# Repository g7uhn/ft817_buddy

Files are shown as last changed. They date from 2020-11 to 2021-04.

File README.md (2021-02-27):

# ft817_buddy
A companion display &amp; controls for the FT-817.

FT817 Buddy Rev 1 in the field

This is a work in progess, [more information at my page](http://alloutput.com/ft-817-buddy/).

A little story about the build is over at [SWLing Post](https://swling.com/blog/2020/08/andy-builds-a-genius-companion-control-display-for-the-yaesu-ft-817-transceiver/).

Rev4 hardware files now released :-)

Enjoy!

<br />This work is licensed under a <a rel="license" href="http://creativecommons.org/licenses/by-sa/4.0/">Creative Commons Attribution-ShareAlike 4.0 International License</a>.

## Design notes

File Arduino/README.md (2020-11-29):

Arduino files for the FT817_buddy project

This folder conatins sub-folders for:
- src - the main Arduino sketch
- lib - non-standard libraries used by the sketch that you will need to import into your IDE

<br />This work is licensed under a <a rel="license" href="http://creativecommons.org/licenses/by-sa/4.0/">Creative Commons Attribution-ShareAlike 4.0 International License</a>.

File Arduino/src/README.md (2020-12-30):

The main Arduino sketch for the FT-817 Buddy project.

This sketch has been built using Visual Studio Code / PlatformIO IDE (instead of Arduino IDE).  If you want to load this code into Arduino IDE you probably just need to remove the #include <Arduino.h> line at the top of the sketch, Google is your friend.  But it's much nicer to work in VSC/PlatformIO, it's a nice step forward from the Arduino IDE.

Don't forget to inmport the non-standard ft817 library into your IDE, found under ft817_buddy/Arduino/lib/

### Current features

- Display current frequency and mode
- Display current A,B,C key functions
- 3 pages of 6 soft-keys
- Backlight
- Clock
- Tune signal on/off (Transmit an AM carrier, suitable for driving auto-ATU)
- Toggle IPO
- Toggle NAR filter
- Toggle Break-In
- Toggle FT-817 internal Keyer
- Toggle RF Gain/ Squelch
- Toggle VFO A/B
- Set FT-817 internal keyer to preset wpm (12, 15, 18 in my case)
- External keyer: [K1EL K16 chip](https://hamcrafters2.com/files/k16man_R10.pdf) integration
  - Command and M1, M2, M3, M4 buttons
  - Onboard piezo buzzer and LED for K16 feedback
  - Control speed using CMD+paddle (K1EL's "Fast Speed Change" feature)

### Licence
<br />This work is licensed under a <a rel="license" href="http://creativecommons.org/licenses/by-sa/4.0/">Creative Commons Attribution-ShareAlike 4.0 International License</a>.

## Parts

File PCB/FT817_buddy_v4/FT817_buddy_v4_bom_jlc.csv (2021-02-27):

Comment | Designator | Footprint | LCSC Part #
100nF | C1,C3,C5,C4,C10,C6 | C_0805_2012Metric_Pad1.15x1.40mm_HandSolder | C49678
10uF | C2 | C_0805_2012Metric_Pad1.15x1.40mm_HandSolder | C15850
10nF | C7 | C_0805_2012Metric_Pad1.15x1.40mm_HandSolder | C1710
1nF | C8,C9 | C_0805_2012Metric_Pad1.15x1.40mm_HandSolder | C46653
Polyfuse_Small | F1 | Fuse_1206_3216Metric_Pad1.42x1.75mm_HandSolder | C369154
47k | R2,R6 | R_0805_2012Metric_Pad1.15x1.40mm_HandSolder | C17713
10k | R3,R4 | R_0805_2012Metric_Pad1.15x1.40mm_HandSolder | C17414
22k | R5 | R_0805_2012Metric_Pad1.15x1.40mm_HandSolder | C17560
100k | R7 | R_0805_2012Metric_Pad1.15x1.40mm_HandSolder | C17407
10K | R8,R10,R11,R16 | R_0805_2012Metric_Pad1.15x1.40mm_HandSolder | C17414
1K | R9,R18,R20,R22 | R_0805_2012Metric_Pad1.15x1.40mm_HandSolder | C17513
2.2K | R12,R13,R14,R15,R1 | R_0805_2012Metric_Pad1.15x1.40mm_HandSolder | C17520
220 | R17 | R_0805_2012Metric_Pad1.15x1.40mm_HandSolder | C17557
470 | R19 | R_0805_2012Metric_Pad1.15x1.40mm_HandSolder | C17710
1500 | R21 | R_0805_2012Metric_Pad1.15x1.40mm_HandSolder | C4310
AMS1117-5.0 | U1 | SOT-223-3_TabPin2 | C6187
ADuM1201AR | U3 | SOIC-8_3.9x4.9mm_P1.27mm | C9669
ULN2803A | U5 | SOIC-18W_7.5x11.6mm_P1.27mm | C9683

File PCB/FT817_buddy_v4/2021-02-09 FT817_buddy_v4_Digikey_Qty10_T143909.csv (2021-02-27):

Index | Quantity | Part Number | Manufacturer Part Number | Description | Customer Reference | Available | Backorder | Unit Price | Extended Price GBP
1 | 20 | CKN9559-ND | OS102011MA1QN1 | SWITCH SLIDE SPDT 100MA 12V |  | 20 | 0 | 0.34100 | 6.82
2 | 10 | 2725-B0505S-1WR3-ND | B0505S-1WR3 | DC DC CONVERTER 5V 1W |  | 10 | 0 | 0.86500 | 8.65
3 | 10 | 490-9647-1-ND | PKMCS0909E4000-R1 | AUDIO PIEZO TRANSDUCER 12.5V SMD |  | 10 | 0 | 0.59000 | 5.90
4 | 20 | CP1-3525N-ND | SJ1-3525N | CONN JACK STEREO 3.5MM R/A |  | 20 | 0 | 0.48900 | 9.78
5 | 50 | 754-1939-1-ND | APT2012LZGCK | LED GREEN CLEAR 2SMD |  | 50 | 0 | 0.28000 | 14.00
6 | 10 | 609-4717-ND | DILB8P-223TLF | CONN IC DIP SOCKET 8POS TIN |  | 10 | 0 | 0.11100 | 1.11

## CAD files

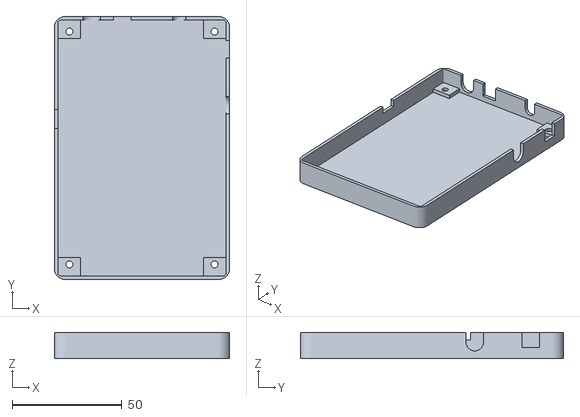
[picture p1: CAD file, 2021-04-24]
Enclosure/enclosure_base_Rev4_v1.stl
80.0 x 120.0 x 12.0

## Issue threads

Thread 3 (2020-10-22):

Brief fluctuations in displayed data

drorthogonal, 2020-10-22:
The display occasionally updates with missing data or incorrect data, for just a few milli seconds, before reverting to the correct info. This is seen in two places while on the 2nd Page (speed change page).
1. Filter display switches from "CW N" to "???N".
2. Frequency display, displays random changes to the Mhz, KHz or 100s Hz or all three.

g7uhn, 2020-10-22:
Yes, these seem to be single read errors from the serial input, recovered on the next poll of the item.  I suspect the read errors are down to use of SoftwareSerial.  Note that the FT-817 serial interface should be using 2 stop bits (8N2) but SoftwareSerial can only do 8N1.  We seem to get away with just 1 stop bit but maybe this is the result.  I've also seen reports that SoftwareSerial can produce relatively frequent read errors... other software serial libraries are available.

Possible ways forward:
- Do nothing.  It's occasional at 9600 baud, probably tolerable.  But at 38400 baud the errors appear frequently;
- Use an alternate software serial library e.g. [NeoSWSerial](https://www.arduino.cc/reference/en/libraries/neoswserial/);
- Move to a microcontroller that has a dedicated hardware serial port for the radio interface.

g7uhn, 2020-11-07:
Moved to hardware serial on Rev2 - looks rock solid now.  :-)

Closed 2020-11-07.

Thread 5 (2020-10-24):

Keyer speed selection

drorthogonal, 2020-10-24:
The current keyer speed options (page 2) are set up at compile time and not configurable from the FT817 Buddy.
This issue is to investigate a possible evolution to this to provide some more flexibility. Options include:
1. Providing a way to configure  and store user preferences for the speeds (would need a way to store values persistently). Probably beyond the scope of this project.
2. Read the current Keyer speed and provide 6 x soft key options (3 x slower and 3 x faster) e.g. if current keyer speed is 18wpm provide softly options for, say, 12, 14, 16, 20, 22 & 24wpm.
3. Read and display the current Keyer speed settings and provide [up] [down] options on the soft keys to increment or decrement the speed in, say, 1wpm steps, reloading the display with the newly set speed.
#enhancement
...I'm adding this one as a possible development for me to try to learn C++!

g7uhn, 2020-11-07:
Good enhancement... might be solved by integration of a K1EL keyer onto the Buddy... let's wait and see how we feel when we try that.

g7uhn, 2020-11-17:
Including the K1EL K16 keyer chip... the CMD+paddle speed adjustment seems to hit points 2 and 3

g7uhn, 2020-11-21:
I think we're there for a first pass at this.

- K1EL external keyer added to Rev3, powers up at a preset favourite wpm and speed +/- is controlled by CMD+paddle, beeps for feedback, see [K16 manual](https://hamcrafters2.com/files/k16man_R10.pdf), page 15, "Fast Speed Change Feature"
- If using the FT-817 internal keyer (unlikely after the addition of K1EL) then preset favourite speeds can be programmed/ modified into Buddy code easily (current code is an example)
- More complex read/modify of the internal keyer is possible if someone wants to put the time in... :smile:

Closed 2020-11-21.

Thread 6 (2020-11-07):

Reduce current draw from FT-817

g7uhn, 2020-11-07:
FT-817 ACC port "13.8V" output pin appears to have a current-limiting 10 Ohm 1/16W 0604-size resistor between it and the radio's 13.8V supply rail.  It's very small so it may be there as a fuse...?  **Translates to 0.0625W or about 5mA @13V.** 😟
(resistor power handling and consequences are noted here: https://www.microwavers.org/files/backscatter/8_IF-Rigs.pdf ...and the Yaesu service manual does indeed show R1235 is a 10 Ohm 1/16W 0604)

But wait!  A note on KA7OEI's site says *"if you leave the CT-62 CAT interface cable plugged into the '817, this will pull 20-30 milliamps from the radio's power source"* ...which suggest that Yaesu's own accessory pulls up to 30mA... and the BHI CAT-MATE suggests you can pull up to 60mA from the port (http://noisecancellingintercom.co.uk/html/cat-mate.html) so maybe 20mA is a very reasonable design target after all?

Anyway, at some point my radio appears to have started struggling to supply much power to this pin (Buddy wouldn't power up completely, Arduino stuck in constant reboot cycle) so I may have exceeded what this resistor is there to limit.  Measured current draw of the Buddy at that time was around 40mA @ 10.5V.  I've solved it by performing the VK4GHZ mod.  Other users will wish to use the Buddy without modifying their radio so we need to aim for lowest possible current draw.

Other, more obvious, motivation to reduce current draw of the Buddy is to not waste battery power when portable.

Arduino Pro Mini (Rev2) draws almost exactly the same current as Arduino Nano (despite what the Internet suggests).

Note the Buddy includes a polyfuse immediately after the voltage input to the PCB to protect the FT-817 supply but there is always a small chance of short-circuit before that fuse causing damage to the FT-817.

To do:
- Prototype SMPS modules on breadboard with blink Arduino sketch (removes pulsed serial noise)
- Search for birdies and raised noise level using an antenna

g7uhn, 2020-11-07:
SMPS modules from Murata and CUI on order for exploratory test

g7uhn, 2020-11-15:
SMPS module tested (muRata) - only reduced current from 30mA to 25mA... adds complex part, difficult to install, risk of RFI... doesn't feel like the juice is worth the squeeze.

g7uhn, 2020-11-26:
The CatDisplay accessory pulls a whopping 130mA from the 817 CAT port!  https://sites.google.com/site/zl1cvd/catdisplay

So I feel pretty good about the 40mA of the Buddy.

Closed 2020-11-15.

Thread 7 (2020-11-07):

Improve main loop

g7uhn, 2020-11-07:
Need slicker timing on the main loop
- make tuning display appear smoother
- make all buttons appear equally responsive
- recognise button press and release so we can "hold down" an output to the K1EL CMD input

Maybe more use of interrupts?
Do more reading on good use of Arduino switches e.g. http://www.martyncurrey.com/switching-things-on-and-off-with-an-arduino/

Closed 2020-11-27.

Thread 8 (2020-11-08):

K1EL Keyer Integration Design

g7uhn, 2020-11-08:
- Determine how the Arduino could drive the K1EL buttons
  - A quad low-side driver would bethe way to go here... but I can't find a quad at reasonable price/size so it's a ULN2803A
- Determine how to best drive a piezo (include some smoothing caps? suggested in K16 manual), compare some piezos for a decent sound
  - Sound examples, +free samples+ and fancy square buzzers: https://www.murata.com/en-global/products/sound/sounder/play
  - What effect does mounting a slim buzzer on the *underside* of the PCB have? Might smooth and/or amplify the sound? But would these benefits go away once an enclosure arrives?
- Slim TRS sockets: https://www.mouser.co.uk/ProductDetail/Schurter/48322330?qs=M1T3mF8ombUPfMcVAC0H1Q%3D%3D
- Suitable 10k linear pots on Mouser: https://www.mouser.co.uk/Passive-Components/Potentiometers-Trimmers-Rheostats/Potentiometers/_/N-9q0ypZ1yzvvqx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

Rough sketch of possible Rev3 layout:
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

Closed 2020-11-08.

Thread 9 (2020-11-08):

K1EL Keyer Integration Code and Test

g7uhn, 2020-11-08:
- Write code to drive keyer buttons
- Determine how to best drive a piezo on breadboard (include some smoothing caps? suggested in K16 manual), compare some piezos for a decent sound
- What effect does mounting a slim buzzer on the underside of the PCB have? Might smooth and/or amplify the sound? But would these benefits go away once an enclosure arrives?

g7uhn, 2020-11-15:
Buzzer working OK direct from K16 sidetone pin to "+" pin.

Buttons driving K16 input pin - needed some experimentation to compensate for the 0.6V volt drop across the low-side driver switching... +need to experiment with better resistor selection and find the edges of K16 decisions+

g7uhn, 2020-11-17:
- Probably settled on resistors.
- Operation more reliable by ditching the speed knob (simplify the resistor network where we have to guess at the transistor switching effects).  CMD+paddle adjustment of the keyer speed feels good!

Closed 2020-11-21.

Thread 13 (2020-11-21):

Pick an open source licence for this project

g7uhn, 2020-11-21:
No inherited licences in this project at this time... except requests for a nod to authors (which is done in the docs, source code and PCB silkscreen).

Licences of interest:
[CC-by-sa (share alike)](https://creativecommons.org/licenses/by-sa/4.0/)
...works for hardware and software

g7uhn, 2020-11-21:
http://www.inmojo.com/licenses/#cc_a_sa_3.0 Description of CC-BY-SA license under Open Source HardWare (OSHW) definition

Closed 2020-11-21.

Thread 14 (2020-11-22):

Documentation

g7uhn, 2020-11-22:
FAQ
Build guide (order the stuff, build it)
Operating notes (subject to change with the code improving)
Design notes
Data pack (schematic, PCB files)
License notes (why it's CC-BY-SA)
Software guide (notes on the Arduino pinout and interfaces, general guide to the sketch and library usage, how to add a feature on the code, how to join in on GitHub)

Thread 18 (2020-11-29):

Investigate serial number generator

g7uhn, 2020-11-29:
Something like enter your callsign, get a serial number...
...write your serial number on your PCB
...callsigns are stored just to see how many of these things are out in the wild
Doesn't mean anything, just for fun!

g7uhn, 2020-11-29:
Wordpress plugin:
- Contact Form 7
- CF7 Google Sheets Connector
- Contact Form 7 Serial Numbers

Sounds complicated but the idea that something goes straight into a Google Sheet is cool.

g7uhn, 2020-11-29:
Concerned that giving out "serial numbers" rather implies some sort of warranty/liability

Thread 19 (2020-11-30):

Rev3 PCB improvements

g7uhn, 2020-11-30:
- ~~Is there a way to support both AZD (8-pin) and Sparkfun (9-pin) displays?~~
- ~~Check tx keying of FT-817 (actual TX, there was some mention of RFI on keying in the K16 doc)~~
- ~~Increase OSHW symbol size~~
- ~~Increase "+" size next to buzzer (may not be necessary?)~~
- ~~Add a 1k resistor in between Arduino and buzzer?  see Murata [data sheet](https://www.murata.com/products/productdata/8801054228510/SPEC-PKMCS0909E4000-R1.pdf?1590156016000)~~
- ~~Consider easier to solder buzzer? Only if terrible feedback from testers...~~
- ~~Improve labelling around cable J1 e.g. Rx, Tx...~~
- ~~Increase clearance of ground plane around cable header J1 for peace of mind, reduce risk of V to G short before fuse~~
- ~~Draw box around B0505~~
- Move callsigns away from tracks where possible
- ~~Licence text and symbol on rear silkscreen?~~
- ~~Move LED pads away from clip holes~~
- ~~Swap 3.5mm socket for through-hole part~~
- ~~Swap left and right paddle inputs to be normal~~

Closed 2021-02-07.

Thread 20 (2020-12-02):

Read currentMode on startup

g7uhn, 2020-12-02:
...so that an accidental press of TUNoff doesn't flick the radio into LSB if you haven't done a TUNon

Or only activate TUNoff if TUNon has been pressed. (toggle a bool)

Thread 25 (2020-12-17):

Add a UTC clock onto the board

g7uhn, 2020-12-17:
Could be a RTC added to the Nokia screen items? (probably requires a coin battery and other stuff adding to the PCB...)
Could be just a separate LCD clock mounted on the board?
Or just buy a cheap digital watch and stick it on the 817?

g7uhn, 2020-12-22:
Will require an RTC IC and a button battery (and a few other passive components) adding to the PCB.
Will also significantly increase complexity of code (need a menu screen for setting the time).
Probably skip this to keep the project simple.  Just add a cheap LCD clock velcro'd to the top of the radio...?

Closed 2020-12-22.

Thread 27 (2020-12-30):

Improve clock accuracy

g7uhn, 2020-12-30:
Currently loses 1 minute every 2.5h

g7uhn, 2021-02-08:
Good enough for non-RTC operation.
RTC now implemented, tested overnight, no time slip.

Closed 2021-02-08.

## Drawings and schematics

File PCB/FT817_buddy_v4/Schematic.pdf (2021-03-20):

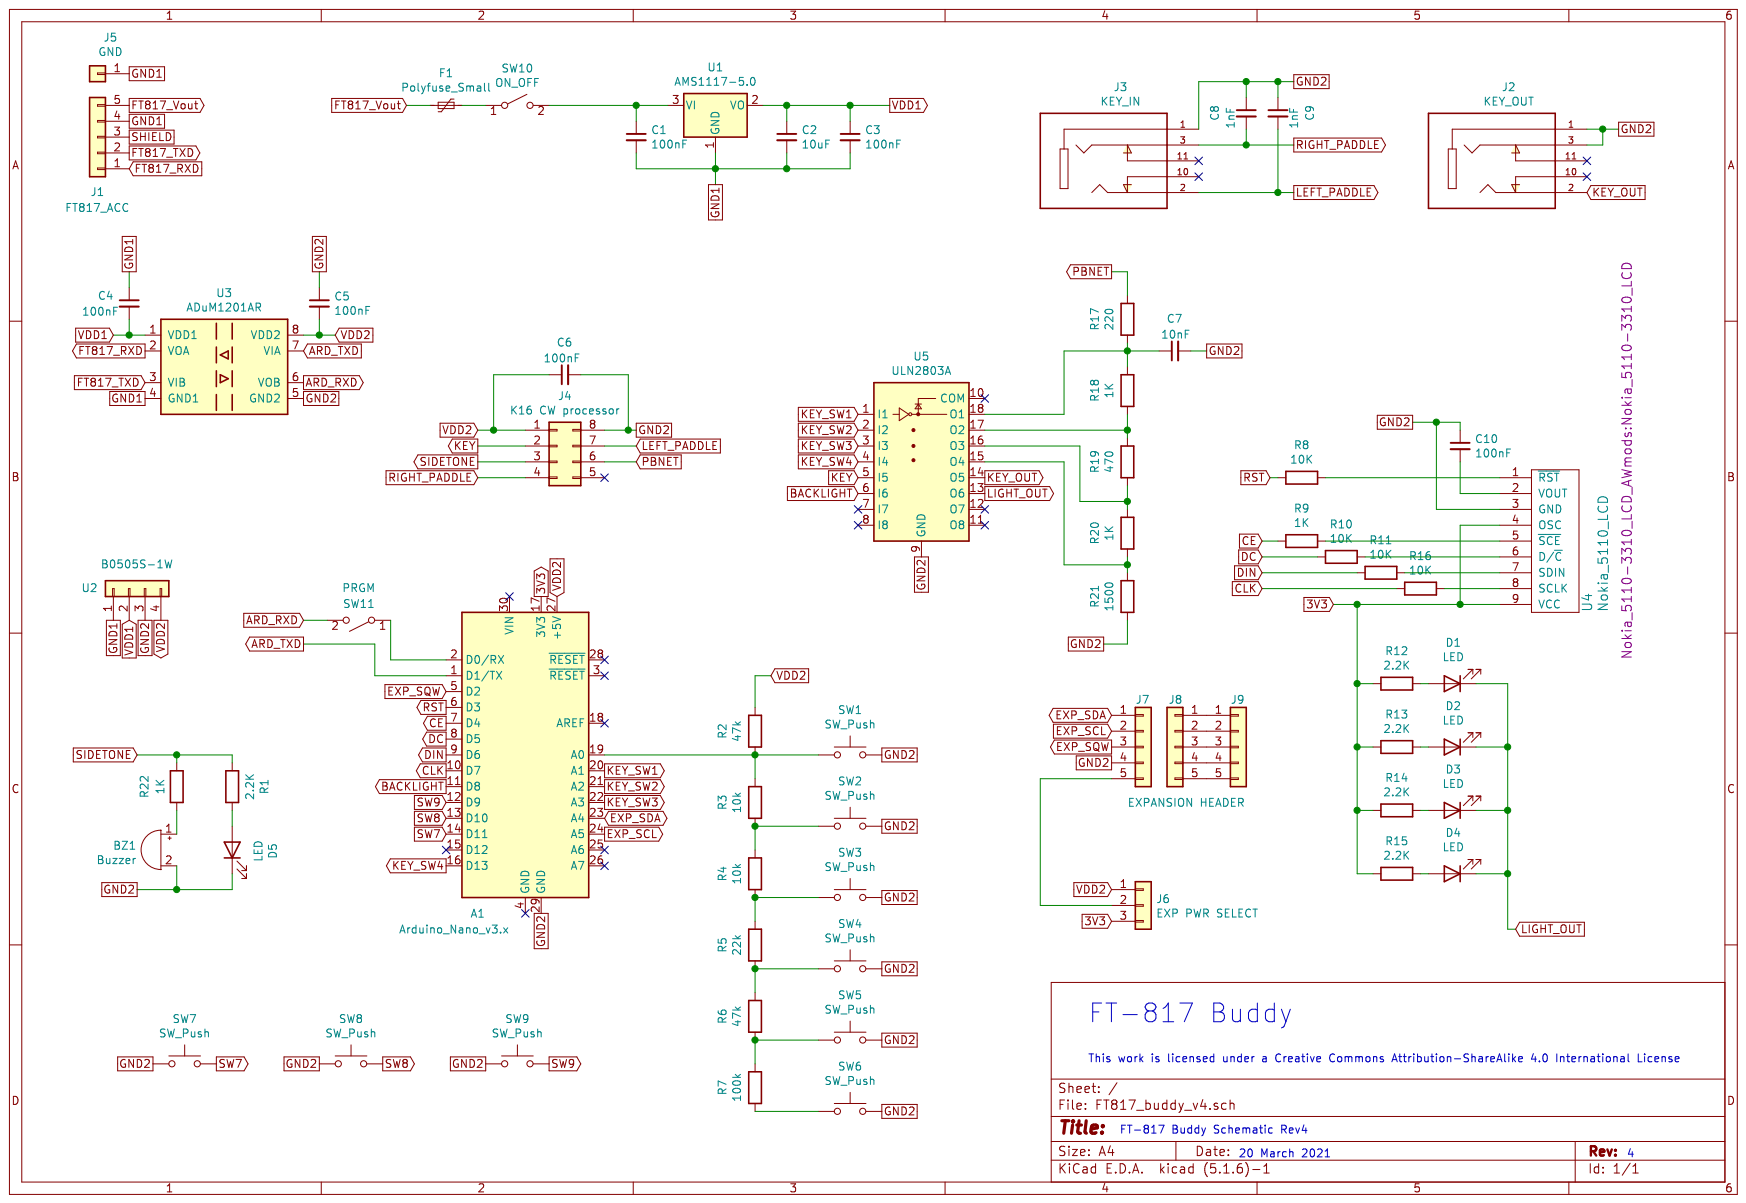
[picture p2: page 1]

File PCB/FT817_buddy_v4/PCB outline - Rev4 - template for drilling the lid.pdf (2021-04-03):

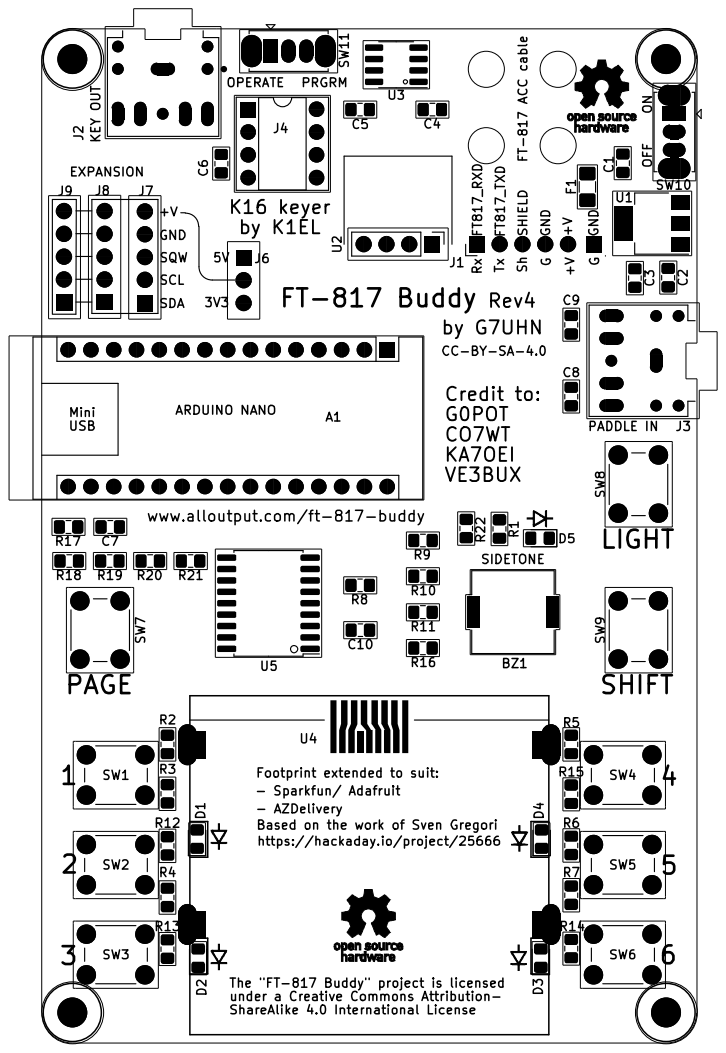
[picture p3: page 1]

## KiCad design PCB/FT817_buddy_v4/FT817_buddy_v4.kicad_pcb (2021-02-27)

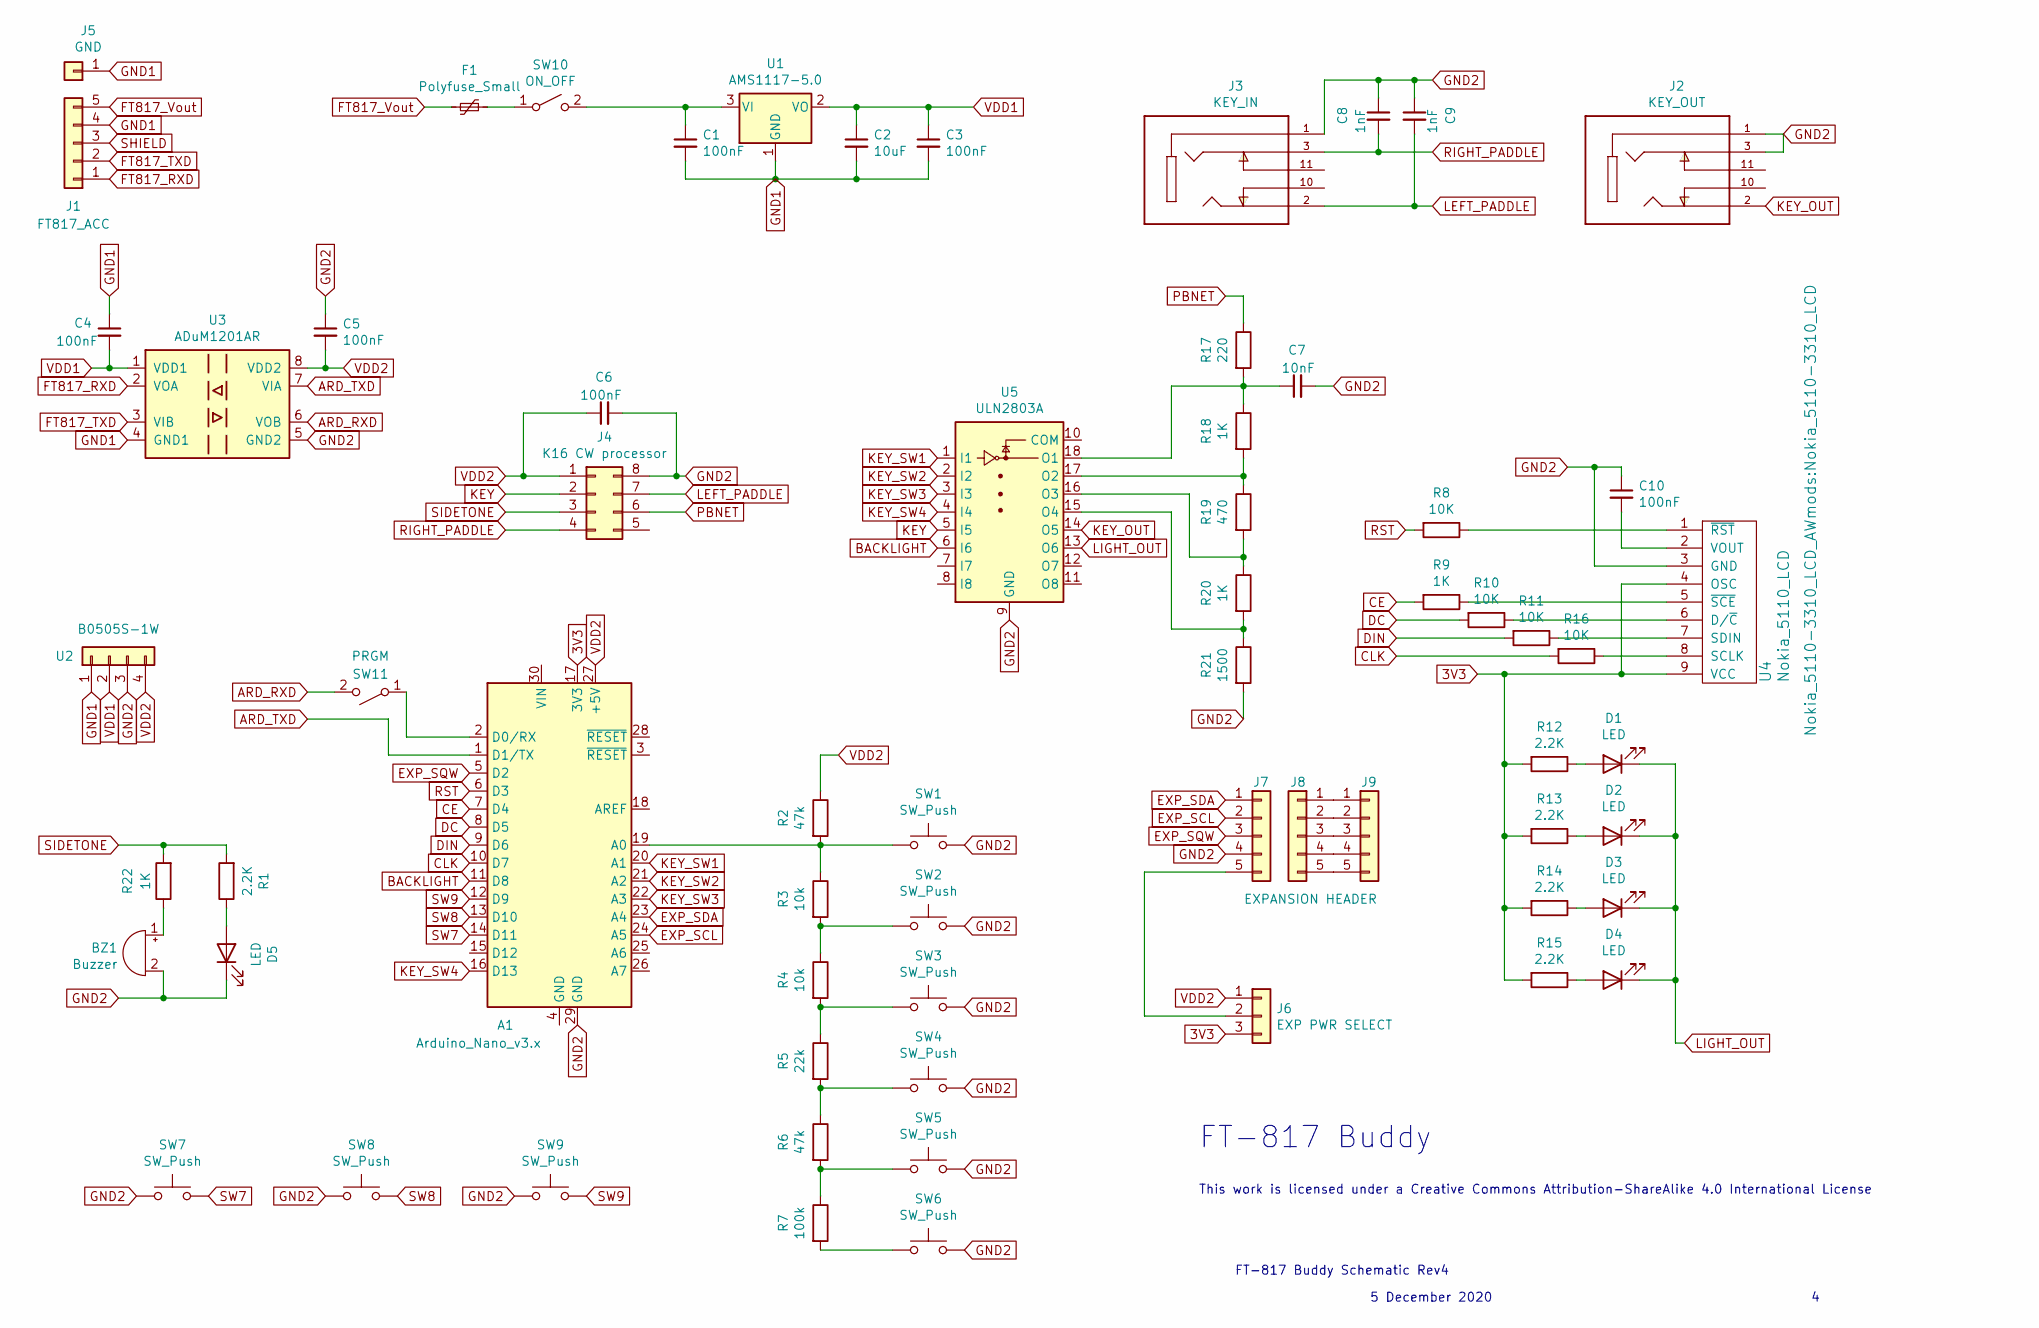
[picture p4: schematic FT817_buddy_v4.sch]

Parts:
A1: Arduino_Nano_v3.x; Arduino_Nano
BZ1: Buzzer; Buzzer_Murata_PKMCS0909E4000-R1
C1, C3, C4, C5, C6, C10: 100nF; C_0805_2012Metric_Pad1.15x1.40mm_HandSolder; JLCPCB C49678
C2: 10uF; C_0805_2012Metric_Pad1.15x1.40mm_HandSolder; JLCPCB C15850
C7: 10nF; C_0805_2012Metric_Pad1.15x1.40mm_HandSolder; JLCPCB C1710
C8, C9: 1nF; C_0805_2012Metric_Pad1.15x1.40mm_HandSolder; JLCPCB C46653
D1, D2, D3, D4, D5: LED; LED_0805_2012Metric_Pad1.15x1.40mm_HandSolder
F1: Polyfuse_Small; Fuse_1206_3216Metric_Pad1.42x1.75mm_HandSolder; JLCPCB C369154
J1: FT817_ACC; PinHeader_1x05_P2.54mm_Horizontal
J2: KEY_OUT; CUI_SJ1-3525N; PARTREV 1.02
J3: KEY_IN; CUI_SJ1-3525N; PARTREV 1.02
J4: K16 CW processor; DIP-8_W7.62mm_Socket
J5: GND; PinHeader_1x01_P2.54mm_Vertical
J6: EXP PWR SELECT; PinHeader_1x03_P2.54mm_Vertical
J7, J8: PinHeader_1x05_P2.54mm_Vertical
J9: EXPANSION HEADER; PinSocket_1x05_P2.54mm_Vertical
R1, R12, R13, R14, R15: 2.2K; R_0805_2012Metric_Pad1.15x1.40mm_HandSolder; JLCPCB C17520
R2, R6: 47k; R_0805_2012Metric_Pad1.15x1.40mm_HandSolder; JLCPCB C17713
R3, R4: 10k; R_0805_2012Metric_Pad1.15x1.40mm_HandSolder; JLCPCB C17414
R5: 22k; R_0805_2012Metric_Pad1.15x1.40mm_HandSolder; JLCPCB C17560
R7: 100k; R_0805_2012Metric_Pad1.15x1.40mm_HandSolder; JLCPCB C17407
R8, R10, R11, R16: 10K; R_0805_2012Metric_Pad1.15x1.40mm_HandSolder; JLCPCB C17414
R9, R18, R20, R22: 1K; R_0805_2012Metric_Pad1.15x1.40mm_HandSolder; JLCPCB C17513
R17: 220; R_0805_2012Metric_Pad1.15x1.40mm_HandSolder; JLCPCB C17557
R19: 470; R_0805_2012Metric_Pad1.15x1.40mm_HandSolder; JLCPCB C17710
R21: 1500; R_0805_2012Metric_Pad1.15x1.40mm_HandSolder; JLCPCB C4310
SW1, SW2, SW3, SW4, SW5, SW6, SW7, SW8, SW9: SW_Push; SW_PUSH_6mm
SW10: ON_OFF; SW_Slide_1P2T_CK_OS102011MS2Q
SW11: PRGM; SW_Slide_1P2T_CK_OS102011MS2Q
U1: AMS1117-5.0; SOT-223-3_TabPin2; JLCPCB C6187
U2: B0505S-1W; PinHeader_1x04_P2.54mm_Vertical
U3: ADuM1201AR; SOIC-8_3.9x4.9mm_P1.27mm; JLCPCB C9669
U4: Nokia_5110_LCD; Nokia_5110-3310_LCD
U5: ULN2803A; SOIC-18W_7.5x11.6mm_P1.27mm; JLCPCB C9683

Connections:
3V3: A1.17 (3V3), J6.3, R12.2, R13.2, R14.2, R15.2, U4.4 (OSC), U4.9 (VCC)
ARD_RXD: SW11.2 (B), U3.6 (VOB)
ARD_TXD: A1.1 (D1/TX), U3.7 (VIA)
BACKLIGHT: A1.11 (D8), U5.6 (I6)
CE: A1.7 (D4), R9.2
CLK: A1.10 (D7), R16.2
DC: A1.8 (D5), R10.2
DIN: A1.9 (D6), R11.2
EXP_SCL: A1.24 (A5), J7.2
EXP_SDA: A1.23 (A4), J7.1
EXP_SQW: A1.5 (D2), J7.3
FT817_RXD: J1.1, U3.2 (VOA)
FT817_TXD: J1.2, U3.3 (VIB)
FT817_Vout: F1.2, J1.5
GND1: C1.2, C2.2, C3.2, C4.1, J1.4, J5.1, U1.1 (GND), U2.1, U3.4 (GND1)
GND2: A1.29 (GND), BZ1.2 (+), C5.1, C6.2, C7.2, C8.1, C9.1, C10.1, D5.1 (K), J2.1, J2.3, J3.1, J4.8, J7.4, R21.2, SW1.2, SW2.2, SW3.2, SW4.1, SW5.1, SW6.1, SW7.1, SW8.1, SW9.1, U2.3, U3.5 (GND2), U4.3 (GND), U5.9 (GND)
KEY: J4.2, U5.5 (I5)
KEY_OUT: J2.2, U5.14 (O5)
KEY_SW1: A1.20 (A1), U5.1 (I1)
KEY_SW2: A1.21 (A2), U5.2 (I2)
KEY_SW3: A1.22 (A3), U5.3 (I3)
KEY_SW4: A1.16 (D13), U5.4 (I4)
LEFT_PADDLE: C9.2, J3.2, J4.7
LIGHT_OUT: D1.1 (K), D2.1 (K), D3.1 (K), D4.1 (K), U5.13 (O6)
unnamed: A1.2 (D0/RX), SW11.1 (A)
unnamed: A1.19 (A0), R2.2, R3.1, SW1.1
unnamed: BZ1.1 (-), R22.1
unnamed: C1.1, SW10.2 (B), U1.3 (VI)
unnamed: C7.1, R17.2, R18.1, U5.18 (O1)
unnamed: C10.2, U4.2 (VOUT)
unnamed: D1.2 (A), R12.1
unnamed: D2.2 (A), R13.1
unnamed: D3.2 (A), R14.1
unnamed: D4.2 (A), R15.1
unnamed: D5.2 (A), R1.1
unnamed: F1.1, SW10.1 (A)
unnamed: J6.2, J7.5
unnamed: J8.1, J9.1
unnamed: J8.2, J9.2
unnamed: J8.3, J9.3
unnamed: J8.4, J9.4
unnamed: J8.5, J9.5
unnamed: R3.2, R4.1, SW2.1
unnamed: R4.2, R5.1, SW3.1
unnamed: R5.2, R6.1, SW4.2
unnamed: R6.2, R7.1, SW5.2
unnamed: R7.2, SW6.2
unnamed: R8.1, U4.1 (~RST)
unnamed: R9.1, U4.5 (~SCE)
unnamed: R10.1, U4.6 (D/~C)
unnamed: R11.1, U4.7 (SDIN)
unnamed: R16.1, U4.8 (SCLK)
unnamed: R18.2, R19.1, U5.17 (O2)
unnamed: R19.2, R20.1, U5.16 (O3)
unnamed: R20.2, R21.1, U5.15 (O4)
PBNET: J4.6, R17.1
RIGHT_PADDLE: C8.2, J3.3, J4.4
RST: A1.6 (D3), R8.2
SHIELD: J1.3
SIDETONE: J4.3, R1.2, R22.2
SW7: A1.14 (D11), SW7.2
SW8: A1.13 (D10), SW8.2
SW9: A1.12 (D9), SW9.2
VDD1: C2.1, C3.1, C4.2, U1.2 (VO), U2.2, U3.1 (VDD1)
VDD2: A1.27 (+5V), C5.2, C6.1, J4.1, J6.1, R2.1, U2.4, U3.8 (VDD2)

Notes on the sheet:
This work is licensed under a Creative Commons Attribution-ShareAlike 4.0 International License
FT-817 Buddy Schematic Rev4
5 December 2020
FT-817 Buddy

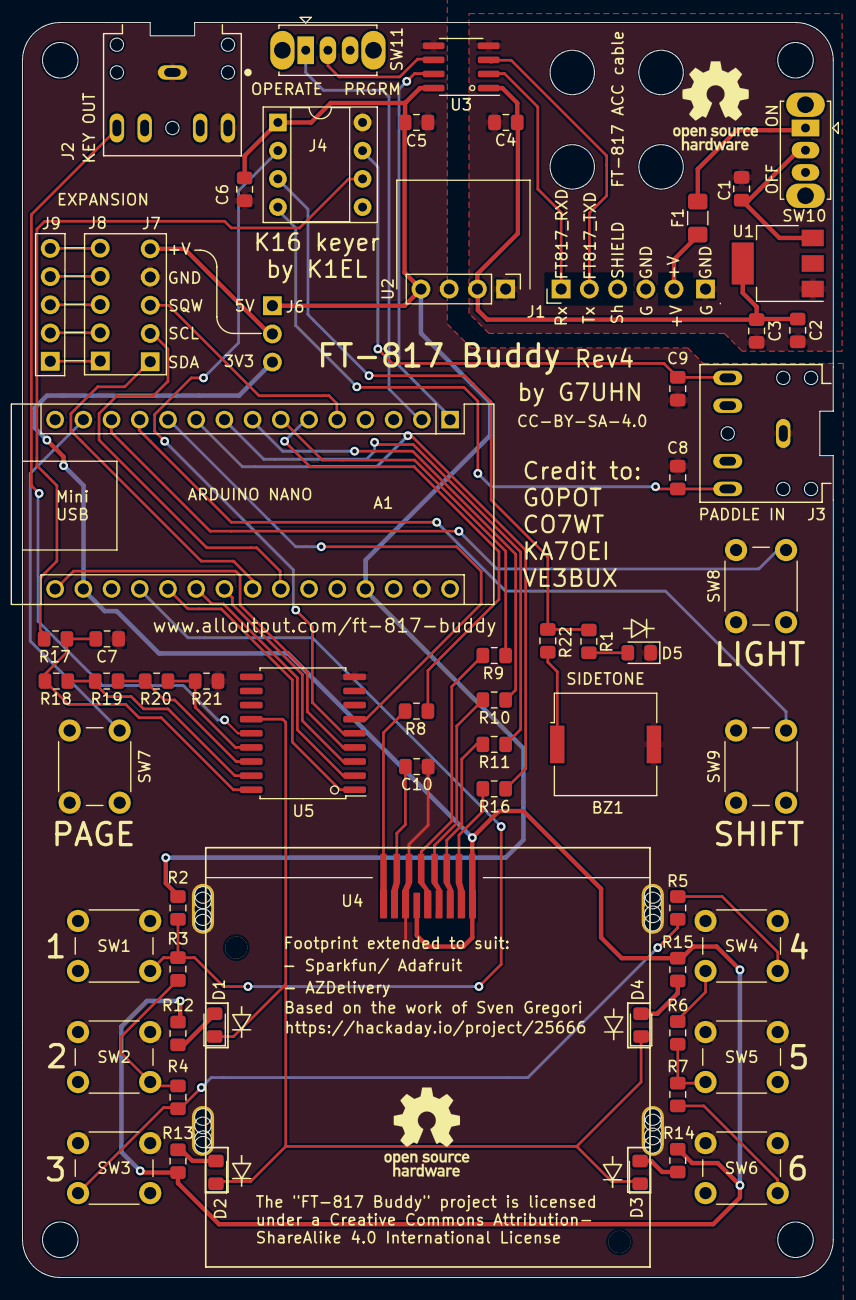
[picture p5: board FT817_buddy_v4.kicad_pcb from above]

Board: 2 copper layers, 73.0 x 113.0 mm, 70 parts (0 on the bottom side), 64 nets.

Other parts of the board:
 : diode_small
 #2,  #3,  #4,  #5: diode_small

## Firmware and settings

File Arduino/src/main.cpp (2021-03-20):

/*
  FT-817 Buddy v1.0
  A companion display and programmable soft-buttons for thr Yaesu FT-817.
  Project description:  http://alloutput.com/amateur-radio/ft-817-companion-display-controls/
  Project files:        https://github.com/g7uhn/ft817_buddy

  Building on the work of Clint Turner KA7OEI (http://www.ka7oei.com/ft817_meow.html) 
  and James Buck VE3BUX (https://ve3bux.com/study-guide/arduino-ft-857d-cat-library/)

  Put together by a team:
  Andy Webster G7UHN
  Michael Sansom G0POT
  Pavel Milanes Costa CO7WT

  IMPORTANT NOTE!  You MUST do/check two things before using this code:
  1) By using this code you acknowledge that you accept the risk that comes with writing to the FT-817 EEPROM i.e. an interruption
     or write error may reset your radio to pre-alignment factory defaults.  See KA7OEI's page here (http://www.ka7oei.com/ft817_meow.html)
     for details of how to record your own radio's unique factory settings such that you can restore your radio if the worst happens!
  2) Uncomment the line below to unlock the sketch that may write to the EEPROM.  You did record your own radio's 76 factory
     calibration settings from the "soft calibration" menu... didn't you?
  
  The authors above bear no responsibility for your use of this code and you proceed at your own risk.  
  
  This work is licensed under a Creative Commons Attribution-ShareAlike 4.0 International License
*/

// uncomment the line below if you want to use this sketch that writes to the EEPROM and accept the responsibility stated above!  :-)
//#define EEPROM_WRITES

// uncomment the line below if you have fitted the Sparkfun DS1307 RTC module to the expansion header
// if no RTC module is fitted, this line should be commented out
//#define RTC_FITTED

// Include libraries
#include <Arduino.h>    // required for PlatformIO IDE (not required if you're using Arduino IDE)
#include <SPI.h>
#include <Adafruit_PCD8544.h>
#include <Adafruit_GFX.h>
#include <Adafruit_I2CDevice.h>
#include <SoftwareSerial.h>
#include <ft817.h>
#include <SparkFunDS1307RTC.h>
#include <Wire.h>

// Declarations
Adafruit_PCD8544 display = Adafruit_PCD8544(7, 6, 5, 4, 3);    // pins for (CLK,DIN,D/C,CE,RST)
FT817 radio;              // define “radio” so that we may pass CAT and EEPROM commands

// Expansion software serial port: TX = digital pin 12, RX = digital pin 11
SoftwareSerial expansion(12,11);

// Define PCB pins
#define backlightPin 8       // backlight output pin (not the "LIGHT" input button!)
#define buttonPin A0         // SW1-SW6 arrive as different levels on analog input A0
#define sw7pin 11            // SW7 input is D11
#define sw8pin 10            // SW8 input is D10
#define sw9pin 9             // SW9 input is D9
#define keyerSw1 15          // A1 (pin 15) is Keyer SW1
#define keyerSw2 16          // A2 (pin 16) is Keyer SW2
#define keyerSw3 17          // A3 (pin 17) is Keyer SW3
#define keyerSw4 13          // D13 is Keyer SW4
#define SQW_INPUT_PIN 2      // Input pin to read RTC square wave


// Global variables - g7uhn TO DO: Needs a big tidy up here
bool sw7status = 1;       // using pullup, pressing button takes this low
bool sw8status = 1;       // using pullup, pressing button takes this low
bool sw9status = 1;       // using pullup, pressing button takes this low
bool backlightStatus = 0; // Backlight, initialises as OFF
bool timedBacklight = 0;  // is the Buddy performing a timed backlight operation?
bool expansionPage = 0;   // is the Buddy displaying the expansion page?
int backlightCounter = 0;
long freq;
String mode;
byte modeByte;
byte modeBase;    // used for the radio to return to this mode after generating Tune signal... needed to accomodate the CW/CWR/DIG NAR codes
byte modeReturn;
byte abcKeys = B1111;
int buttonStatus = 0;   // analog value of buttonPin...
int button = 0;         // ...button number
byte sMeter;
byte MSB;
byte LSB;
int currentPage = 2;    // initialise at the last page
bool softkeyStatus[6] = {0, 0, 0, 0, 0, 0};
short int hh = 0;             // clock hour
short int mm = 0;             // clock minute
short int ss = 0;             // clock seconds
long tickOver = 0;            // a counter to store time values (?)

// Forward declaration of functions (required for PlatformIO)
// If you create your own user functions below, you'll need to declare them here for PlatformIO to compile
void drawMainDisplay();       // draw main display
void displayABCkeys();        // EEPROM read
void displaySoftKeyStatus();  // possible EEPROM reads
void getReadableMode();       // standard CAT command
void backlight();             // no FT-817 interaction
void changePage();            // no FT-817 interaction
void tuneSignalOn();          // standard CAT commands
void tuneSignalOff();         // standard CAT commands
void pressKeyerSw1();         // no FT-817 interaction
void pressKeyerSw2();         // no FT-817 interaction
void pressKeyerSw3();         // no FT-817 interaction
void pressKeyerSw4();         // no FT-817 interaction
void longPressKeyerSw1();     // no FT-817 interaction
void incrementSeconds();      // no FT-817 interaction


/////////////   SETUP YOUR SOFT-KEY PAGES HERE!   ////////////////////////
// Single functions from the ft817 library can be called straight from the pageXSoftKeyFunctionY function
// or, if the desired function is a combination of actions, define a function in the USER FUNCTIONS section below
// to be called by the sketch.  If you make a new function, don't forget to forward declare your user function above.

// Page0 items
// SOFT-KEY 1 
String   page0SoftkeyLabel1 = "TUNon ";           // 6 characters
void  page0SoftkeyFunction1() {tuneSignalOn();}
boolean page0SoftkeyStatus1() {}
// SOFT-KEY 2
String   page0SoftkeyLabel2 = "IPO";              // 3 characters
void  page0SoftkeyFunction2() {radio.toggleIPO();}          // EEPROM write
boolean page0SoftkeyStatus2() {return radio.getIPO();}      // EEPROM read
// SOFT-KEY 3 
String   page0SoftkeyLabel3 = "KYR";              // 3 characters
void  page0SoftkeyFunction3() {radio.toggleKeyer();}        // EEPROM write
boolean page0SoftkeyStatus3() {return radio.getKeyer();}    // EEPROM read
// SOFT-KEY 4 
String   page0SoftkeyLabel4 = "TUNoff";           // 6 characters
void  page0SoftkeyFunction4() {tuneSignalOff();}
boolean page0SoftkeyStatus4() {}
// SOFT-KEY 5 
String   page0SoftkeyLabel5 = " BK";              // 3 characters
void  page0SoftkeyFunction5() {radio.toggleBreakIn();}      // EEPROM write
boolean page0SoftkeyStatus5() {return radio.getBreakIn();}  // EEPROM read
// SOFT-KEY 6 
String   page0SoftkeyLabel6 = "NAR";              // 3 characters
void  page0SoftkeyFunction6() {radio.toggleNar();}          // EEPROM write
boolean page0SoftkeyStatus6() {return radio.getNar();}      // EEPROM read


// Page1 items
// SOFT-KEY 1 
String   page1SoftkeyLabel1 = "getRTC";           // 6 characters
void  page1SoftkeyFunction1() {rtc.update(); ss = rtc.second(); mm = rtc.minute(); hh = rtc.hour();}  // get update from RTC and update Arduino's hh/mm/ss
boolean page1SoftkeyStatus1() {}
// SOFT-KEY 2 
String   page1SoftkeyLabel2 = "hh+";              // 3 characters
void  page1SoftkeyFunction2() {hh = (hh + 1) % 24; tickOver = millis(); delay(300);}
boolean page1SoftkeyStatus2() {}
// SOFT-KEY 3 
String   page1SoftkeyLabel3 = "hh-";              // 3 characters
void  page1SoftkeyFunction3() {if(hh==0) {hh=23;} else{hh = (hh - 1) % 24;}; tickOver = millis(); delay(300);}
boolean page1SoftkeyStatus3() {}
// SOFT-KEY 4 
String   page1SoftkeyLabel4 = "setRTC";           // 6 characters
void  page1SoftkeyFunction4() {rtc.setTime(0, mm, hh, 1, 1, 1, 21);}  // set RTC to hh:mm on the 1/1/21 (we're not interested in dates here, only time)
boolean page1SoftkeyStatus4() {}
// SOFT-KEY 5 
String   page1SoftkeyLabel5 = "mm+";              // 3 characters
void  page1SoftkeyFunction5() {mm = (mm + 1) % 60; tickOver = millis(); delay(300);}
boolean page1SoftkeyStatus5() {}
// SOFT-KEY 6
String   page1SoftkeyLabel6 = "mm-";              // 3 characters
void  page1SoftkeyFunction6() {if(mm==0) {mm=59;} else{mm = (mm - 1) % 60;}; tickOver = millis(); delay(300);}
boolean page1SoftkeyStatus6() {}


// Page2 items
// SOFT-KEY 1 
String   page2SoftkeyLabel1 = "CMD   ";           // 6 characters
void  page2SoftkeyFunction1() {longPressKeyerSw1();}
boolean page2SoftkeyStatus1() {}
// SOFT-KEY 2 
String   page2SoftkeyLabel2 = "M1 ";              // 3 characters
void  page2SoftkeyFunction2() {pressKeyerSw1();}
boolean page2SoftkeyStatus2() {}
// SOFT-KEY 3 
String   page2SoftkeyLabel3 = "M2 ";              // 3 characters
void  page2SoftkeyFunction3() {pressKeyerSw2();}
boolean page2SoftkeyStatus3() {}
// SOFT-KEY 4 
String   page2SoftkeyLabel4 = "   NAR";           // 6 characters
void  page2SoftkeyFunction4() {radio.toggleNar();}
boolean page2SoftkeyStatus4() {return radio.getNar();}
// SOFT-KEY 5 
String   page2SoftkeyLabel5 = " M3";              // 3 characters
void  page2SoftkeyFunction5() {pressKeyerSw3();}
boolean page2SoftkeyStatus5() {}
// SOFT-KEY 6
String   page2SoftkeyLabel6 = " M4";              // 3 characters
void  page2SoftkeyFunction6() {pressKeyerSw4();}
boolean page2SoftkeyStatus6() {}

///////////////  END OF SOFT-KEY PAGE SETUP   ////////////////////
//////////////////////////////////////////////////////////////////


void setup(void) 
{
  // Start serial
  radio.begin(38400);         // start the serial port for the CAT library

  #ifdef RTC_FITTED
  // Initialise RTC library
  rtc.begin();
  rtc.writeSQW(SQW_SQUARE_1);   // Sets SQW output to 1Hz
  attachInterrupt(digitalPinToInterrupt(SQW_INPUT_PIN), incrementSeconds, RISING);
  #endif
  
  // Start expansion software serial
  //expansion.begin(115200);    // start the expansion serial port at 115200 baud for GPS module

  // Set up some pins
  pinMode(backlightPin, OUTPUT);
  pinMode(sw7pin, INPUT_PULLUP);
  pinMode(sw8pin, INPUT_PULLUP);
  pinMode(sw9pin, INPUT_PULLUP);
  pinMode(keyerSw1, OUTPUT);
  pinMode(keyerSw2, OUTPUT);
  pinMode(keyerSw3, OUTPUT);
  pinMode(keyerSw4, OUTPUT);
  pinMode(SQW_INPUT_PIN, INPUT_PULLUP);

  digitalWrite(backlightPin, LOW);
  digitalWrite(keyerSw1, LOW);
  digitalWrite(keyerSw2, LOW);
  digitalWrite(keyerSw3, LOW);
  digitalWrite(keyerSw4, LOW);

  // Initialize Display
  display.begin();
  display.setContrast(62);    // you can change the contrast around to adapt the display for the best viewing! 57 is default and good for Sparkfun
  display.clearDisplay();     // Clear the buffer.

  // Set up the timer interrupt to watch for button status at 50 Hz (needed to catch a quick button press)
  cli();          // stop interrupts
  TCCR1A = 0;     // set entire TCCR1A register to 0
  TCCR1B = 0;     // same for TCCR1B
  TCNT1  = 0;     // initialize counter value to 0
  // set compare match register for 1hz increments
  OCR1A = 311;   // = (16*10^6) / (1*1024*50) - 1 (must be <65536)
  TCCR1B |= (1 << WGM12);               // turn on CTC mode
  TCCR1B |= (1 << CS12) | (1 << CS10);  // Set CS10 and CS12 bits for 1024 prescaler
  TIMSK1 |= (1 << OCIE1A);              // enable timer compare interrupt
  sei();                                // allow interrupts


  // Initial draw of the main display by calling changePage()
  drawMainDisplay();
  changePage();

  #ifdef RTC_FITTED
  // Get RTC time (non-blocking and clock will start at 00:00 if no RTC available????)
  rtc.update();
  ss = rtc.second();
  mm = rtc.minute();
  hh = rtc.hour();
  #endif

  #ifndef EEPROM_WRITES   // if user has not accepted risk/responsibility of EEPROM writes, display a reminder  :-)
    display.setCursor(0, 0);
    display.setTextSize(1);
    display.setTextColor(BLACK, WHITE);
    display.println(" Please agree ");
    display.println(" to EEPROM    ");
    display.println(" writes to    ");
    display.println(" continue...  ");
    display.println(" See notes in ");
    display.println(" the code     ");
    display.display();
  #endif

} // end setup


void loop()  // MAIN LOOP
{
  #ifdef EEPROM_WRITES    // if user has accepted the risk/responsibility of EEPROM writes, go ahead and run the main code block...

  // Using two loops to avoid polling the radio too quickly with things we don't need a fast refresh on:
  // 1) a "fast refresh" loop is run within the main loop for status items that we do want a quick refresh rate e.g. frequency and mode display
  // 2) actions we only need a "slow refresh" are performed outside of the fast loop in the main loop e.g. status bits against soft-key labels

  // FAST REFRESH LOOP starts here
  for (int i = 0; i <=3; i++)
  {
    // Get frequency
    freq = radio.getFreqMode(); //freq is a long integer of 10's of Hz
    int MHz = freq / 100000;
    long remainder = freq % 100000;
    float kHz = remainder / 100.00;

    // Get human readable mode data
    getReadableMode();

  //  // Get Receiver status (S-meter)
  //  byte rxStatusCmd[5] = {0x00, 0x00, 0x00, 0x00, 0xe7};
  //  radioCAT.sendCmd(rxStatusCmd, 5);
  //  sMeter = radioCAT.getByte();
  //  sMeter = sMeter << 4; //left shift the bits by 4 to make this an S-meter byte ranging from 00000000 to 11110000

  // BUTTON ACTIONS

  // If user has pushed one of the soft-keys (1-6)
    if (currentPage == 0)
    {
      if (button == 0) {goto endOfSoftKeyActions;}
      else if (button == 1) { page0SoftkeyFunction1(); softkeyStatus[0] = page0SoftkeyStatus1();}
      else if (button == 2) { page0SoftkeyFunction2(); softkeyStatus[1] = page0SoftkeyStatus2();}
      else if (button == 3) { page0SoftkeyFunction3(); softkeyStatus[2] = page0SoftkeyStatus3();}
      else if (button == 4) { page0SoftkeyFunction4(); softkeyStatus[3] = page0SoftkeyStatus4();}
      else if (button == 5) { page0SoftkeyFunction5(); softkeyStatus[4] = page0SoftkeyStatus5();}
      else if (button == 6) { page0SoftkeyFunction6(); softkeyStatus[5] = page0SoftkeyStatus6();}
      button = 0;  // reset button variable to zero once we've used it
      displaySoftKeyStatus();
    }
    else if (currentPage == 1)
    {
      if (button == 0) {goto endOfSoftKeyActions;}
      else if (button == 1) { page1SoftkeyFunction1(); softkeyStatus[0] = page1SoftkeyStatus1();}
      else if (button == 2) { page1SoftkeyFunction2(); softkeyStatus[1] = page1SoftkeyStatus2();}
      else if (button == 3) { page1SoftkeyFunction3(); softkeyStatus[2] = page1SoftkeyStatus3();}
      else if (button == 4) { page1SoftkeyFunction4(); softkeyStatus[3] = page1SoftkeyStatus4();}
      else if (button == 5) { page1SoftkeyFunction5(); softkeyStatus[4] = page1SoftkeyStatus5();}
      else if (button == 6) { page1SoftkeyFunction6(); softkeyStatus[5] = page1SoftkeyStatus6();}
      button = 0;  // reset button variable to zero once we've used it
      displaySoftKeyStatus();
    }
    else if (currentPage == 2)
    {
      if (button == 0) {goto endOfSoftKeyActions;}
      else if (button == 1) { page2SoftkeyFunction1(); softkeyStatus[0] = page2SoftkeyStatus1();}
      else if (button == 2) { page2SoftkeyFunction2(); softkeyStatus[1] = page2SoftkeyStatus2();}
      else if (button == 3) { page2SoftkeyFunction3(); softkeyStatus[2] = page2SoftkeyStatus3();}
      else if (button == 4) { page2SoftkeyFunction4(); softkeyStatus[3] = page2SoftkeyStatus4();}
      else if (button == 5) { page2SoftkeyFunction5(); softkeyStatus[4] = page2SoftkeyStatus5();}
      else if (button == 6) { page2SoftkeyFunction6(); softkeyStatus[5] = page2SoftkeyStatus6();}
      button = 0;  // reset button variable to zero once we've used it
      displaySoftKeyStatus();
    }
    endOfSoftKeyActions:

  if (sw7status == LOW)   // PAGE button
  {
    changePage();
    delay(200);           // short delay to prevent occasional "double-press"
    sw7status = HIGH;     // reset sw7status to high
  }

  if (sw8status == LOW)   // LIGHT button
  {
    backlight();
    delay(200);           // short delay to prevent occasional "double-press"
    sw8status = HIGH;     // reset sw8status to high
  }

  sw9status = HIGH;     // reset sw9status to high

    // FAST REFRESH STATUS DISPLAY ITEMS

    // Print dial frequency
    if (expansionPage != 1) {     // don't display freq on the expansion page
      display.setCursor(16, 32);
      display.setTextSize(1);
      display.setTextColor(BLACK, WHITE);
      display.print(MHz);
      display.print(",");
      if (kHz < 100) display.print('0');
      if (kHz < 10) display.print('0');
      display.print(kHz);
      if (MHz < 100) display.print(' ');
      if (MHz < 10) display.print(' ');
      display.print(' ');  // extra character to print over the occasional stray "8"
    }

    // Print current mode
    if (expansionPage != 1) {     // don't display mode on the expansion page
      display.setCursor(27, 22);
      display.setTextSize(1);
      display.setTextColor(BLACK, WHITE);
      display.print(mode);
    }

    //// Print S-meter
    //  tft.setCursor(50,120);
    //  int sMeterWidth = 5*(sMeter / 16);
    //  tft.drawRect(51,119,76,8,WHITE);
    //  tft.fillRect(52,120,sMeterWidth,6,WHITE);
    //  tft.fillRect((52+sMeterWidth),120,(74-sMeterWidth),6,BLACK);

    // Format and print time
    char buffer[6]="";    // This is the buffer for the string the sprintf outputs to
    sprintf(buffer, "%02d:%02d", hh, mm);
    display.setCursor(27, 12);
    display.print(buffer);


    #ifndef RTC_FITTED   // if RTC not fitted, use this clunky way out counting up the time in the main loop (RTC method uses hardware interrupt)
    // Calculate time value (at boot this is uptime or user can set hh:mm values, install RTC module to avoid having to set this every boot)
    if ( millis() - tickOver > 59999) {
      if (mm == 59) {
        hh = (hh + 1) % 24; // If mm == 59, increment hh modulo 24
      }
      mm = (mm + 1) % 60;  // Increment mm modulo 60
      tickOver = millis();
    }
    #endif

    delay(200);

    // write to display
    display.display();

  } // END OF FAST REFRESH LOOP (performed 4 times in every main loop)
  
// SLOW REFRESH STUFF


// Timed backlight countdown operation
if(timedBacklight == true)
{
  if(backlightCounter > 0)
  {
    backlightCounter = backlightCounter - 1;
  }
  else
  {
    digitalWrite(backlightPin, 0);    // turn the backlight off
    backlightStatus = 0;
    timedBacklight = 0;               // end the timed backlight
  }
}

display.display();  // update display

#endif
}  // END OF MAIN LOOP


// Interrupt code reading buttons at 50Hz
ISR(TIMER1_COMPA_vect) 
{ //change the 0 to 1 for timer1 and 2 for timer2
  // Get button status (levels determined by resistor network)
  buttonStatus = analogRead(buttonPin);
  switch (buttonStatus) {
    case 0 ... 79:
      button = 1;
      break;
    case 80 ... 239:
      button = 2;
      break;
    case 240 ... 399:
      button = 3;
      break;
    case 400 ... 569:
      button = 4;
      break;
    case 570 ... 749:
      button = 5;
      break;
    case 750 ... 900:
      button = 6;
      break;
  }
  
  bool sw7 = digitalRead(sw7pin);
  if (!sw7)
  {
    sw7status = LOW;  // holds switch status LOW until it has been used in the main loop
  }

  bool sw8 = digitalRead(sw8pin);
  if (!sw8)
  {
    sw8status = LOW;  // holds switch status LOW until it has been used in the main loop
  }

  bool sw9 = digitalRead(sw9pin);
  if (!sw9)
  {
    sw9status = LOW;  // holds switch status LOW until it has been used in the main loop
  }
}


// Increment the clock driven by RTC 1Hz square wave interrupt
void incrementSeconds()
{
  if (ss == 59) {
    if (mm == 59) {
    hh = (hh + 1) % 24;   // if second = 59 AND minute = 59, increment the hour, modulo 24
    }
    mm = (mm + 1) % 60;   // if second = 59, increment the minute, modulo 60
  }
  ss = (ss + 1) % 60;   // increment the second, modulo 60
}


// Draw main display
void drawMainDisplay()
{
  // Initial display setup
  display.drawFastVLine(41, 0, 10, BLACK);
  display.drawFastVLine(24, 10, 21, BLACK);
  display.drawFastVLine(59, 10, 21, BLACK);
  display.drawFastHLine(0, 9, display.width(), BLACK);
  display.drawFastHLine(0, 20, 24, BLACK);
  display.drawFastHLine(60, 20, 24, BLACK);
  display.drawFastHLine(0, 30, 24, BLACK);
  display.drawFastHLine(60, 30, 24, BLACK);
  
  // Update the ABC keys
  displayABCkeys();

  // write to display
  display.display();
}
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

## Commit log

2020-10-17 bug fix, removed debug print statements
    [main.cpp]
2020-10-18 moved PAGE and LIGHT buttons into slow loop
2020-10-18 Removed debug print statements
2020-10-20 fixed serial baud from int to long to allow 38400
    [main.cpp]
2020-10-20 silenced mode read error
    [main.cpp]
2020-10-25 Code modified for Arduino Pro Mini
2020-11-08 Updated platformio.ini to include both boards
2020-11-08 Revert "Merge Development into Master"
    [main.cpp]
2020-11-08 Unmuted "???" print for mode read error
    [main.cpp]
2020-11-08 Unmunted "???" for mode read error
    [main.cpp]
2020-11-08 Unmuted "???" on mode read error
    [main.cpp]
2020-11-10 Hardware files removed pending Rev2 release
    [FT817_buddy_v1d.sch, FT817_buddy_v1d_filled.kicad_pcb]
2020-11-14 Added keyer pin defines
2020-11-14 Added Keyer push button functions
2020-11-16 Fixed "opt in" statement
    [main.cpp]
2020-11-16 Tightened up risk statement
    [main.cpp]
2020-11-26 Moved displayABCkeys to once on Arduino setup
2020-11-27 SoftKey status to triggered, buttons to fast loop
2020-11-28 Added current features to README
2020-12-02 Allowed EEPROM writes, board = Nano
2020-12-12 Added PCB folder
2020-12-13 Corrected ft817.h case
2020-12-30 fix drawMainDisplay + softKeyStatus on page change
    [main.cpp]
2020-12-30 added clock setting buttons
2020-12-30 updated int. keyer speed prefs, moved clock reset
    [main.cpp]
2020-12-30 corrected millis values on minutes tickOver
    [main.cpp]
2020-12-30 corrected missing spaces on page 2 labels
    [main.cpp]
2020-12-30 Re-ordered hhmm setting buttons to make more sense
2021-02-06 changed pin assignments
2021-02-07 Increment time from RTC square wave interrupt
2021-02-27 Rev4 released
    [2021-02-09 FT817_buddy_v4_Digikey_Qty10_T143909.csv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]
2021-02-27 Added pdf schematic
2021-03-20 Updated with input/ouput and not connected symbols
    [FT817_buddy_v4.sch]
2021-03-20 Changed read buttonStatus to switch/case
2021-04-03 Added 1:1 PCB outline as drilling template
2021-04-24 Added enclosure base STL
    [enclosure_base_Rev4_v1.stl]

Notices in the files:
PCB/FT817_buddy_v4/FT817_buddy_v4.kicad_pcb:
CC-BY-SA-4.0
